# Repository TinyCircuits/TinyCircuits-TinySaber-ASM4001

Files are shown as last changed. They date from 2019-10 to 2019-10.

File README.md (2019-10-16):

# TinyCircuits-TinySaber-ASM4001
# ASM4001 Rev3

The design files are located under design_files/ for the TinyCircuits ASM4001 Rev 3 PCB. This is a touch-sensitive TinySaber made with RGB LEDs powered by Arduino software.

Format is in Cadsoft Eagle format - Eagle version 6.2 was used for the original design.

For more infomation on this, check out the product page at TinyCircuits.com: https://tinycircuits.com/collections/all/products/pocket-arcade

# License:

Design by TinyCircuits.
All design files are released under the Creative Commons Attribution Share-Alike 3.0 License, see the following link for details: http://creativecommons.org/licenses/by-sa/3.0

All text above must be included in any redistribution or derived design

This project uses designs and concepts developed as part of the Arduino project and the LilyPad project. The TinyCircuits design files themselves (schematics, PCB and libraries) are not directly derived from these works' design files and have been created new, however the concepts and basic architecture behind the TinyDuino and TinyLily products are derived and we thank the hard work of the organizations below for their contributions to open-source hardware:
  
Original Arduino Uno Design by Team Arduino

LilyPad Arduino Design by Leah Buechley and Sparkfun Electronics

Please support the open-source hardware community

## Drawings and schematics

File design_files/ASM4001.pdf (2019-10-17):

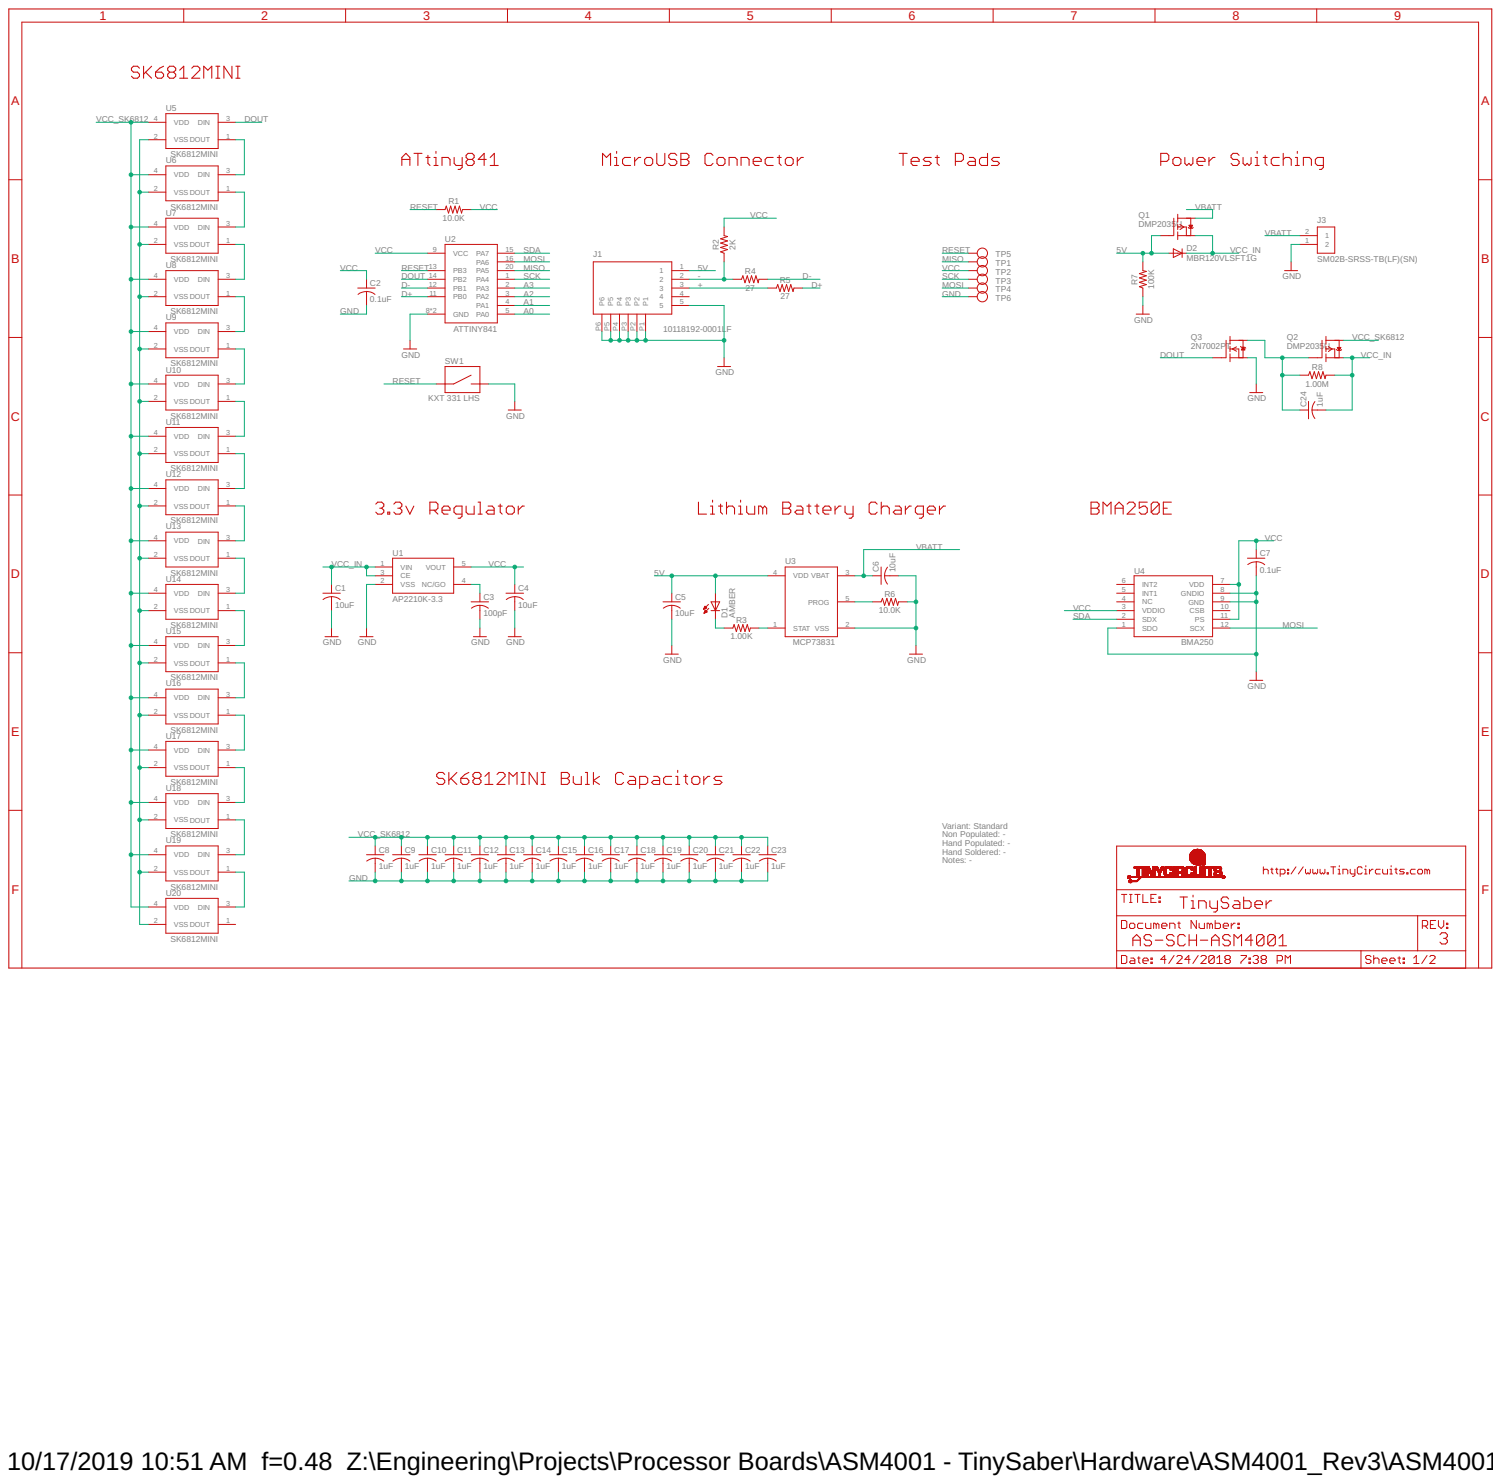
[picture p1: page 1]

SM02B-SRSS-TB(LF)(SN) DMP2035U

Variant: Standard Non Populated: - Hand Populated: - Hand Soldered: - Notes: -

10/17/2019 10:51 AM f=0.48 Z:\Engineering\Projects\Processor Boards\ASM4001 - TinySaber\Hardware\ASM4001_Rev3\ASM4001.sch (Sheet: 1/2)

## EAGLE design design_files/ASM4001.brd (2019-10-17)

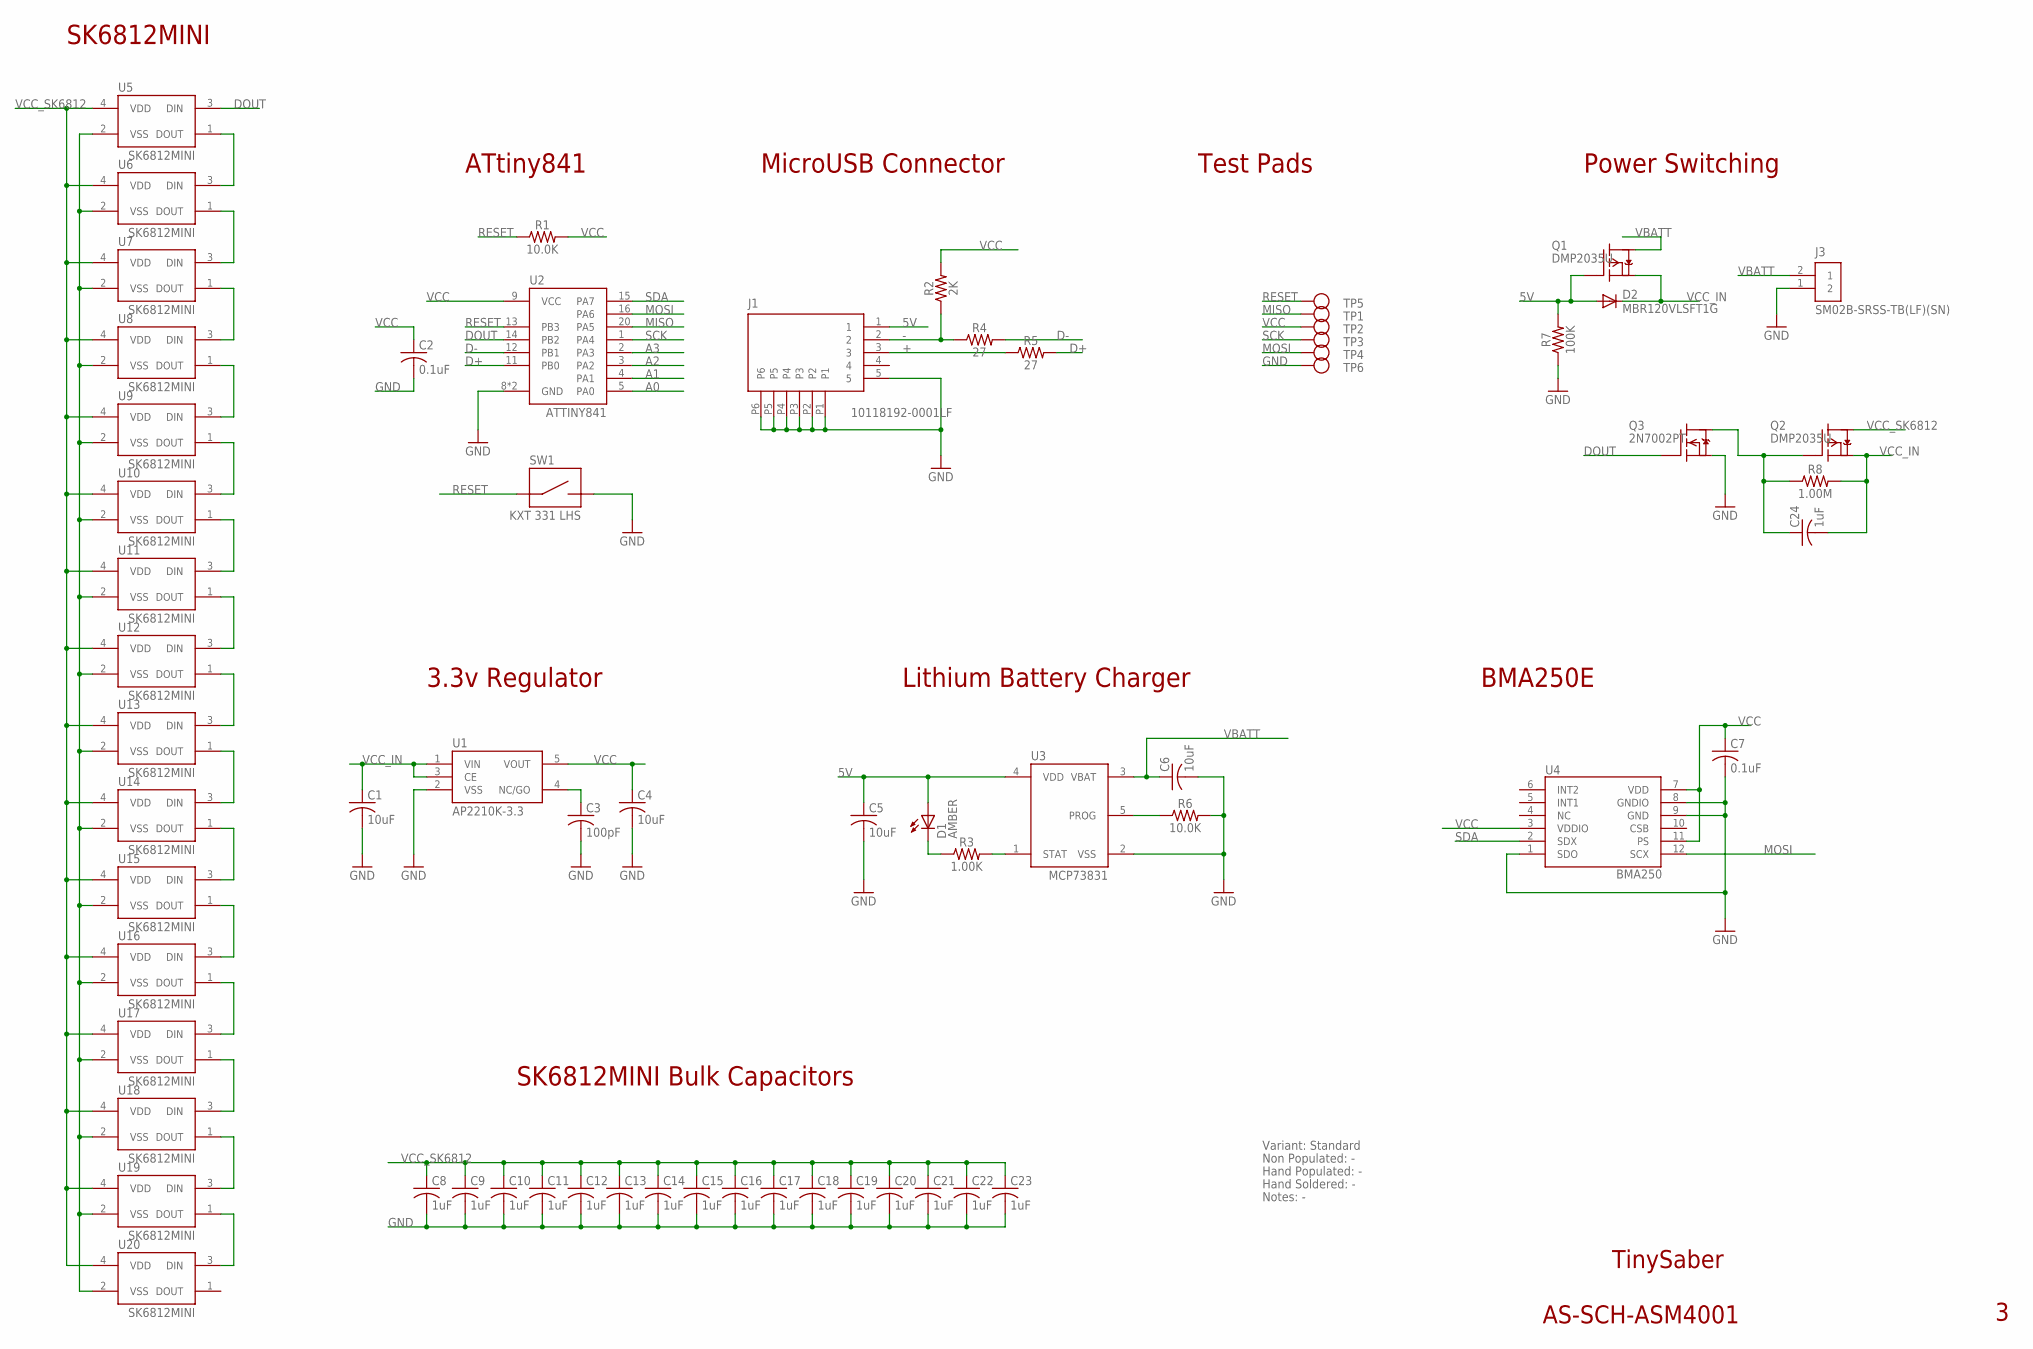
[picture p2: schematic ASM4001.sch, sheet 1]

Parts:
C1, C4, C5: 10uF; C0603; PARTNO AS-ITM-00002
C2, C7: 0.1uF; C0402
C3: 100pF; 0402; PARTNO AS-ITM-00148
C6: 10uF; C0603
C8, C9, C10, C11, C12, C13, C14, C15, C16, C17, C18, C19, C20, C21, C22, C23: 1uF; C0603; PARTNO AS-ITM-00410
C24: 1uF; C0402
D1: AMBER; 0402_LED
D2: MBR120VLSFT1G; SOD-123FL; PARTNO AS-ITM-00111
J1: 10118192-0001LF; MICRO_USB_ALT
J3: SM02B-SRSS-TB(LF)(SN); JST_SH_2X1
Q1: DMP2035U; SOT23
Q2: DMP2035U; SOT23A; PARTNO AS-ITM-00024
Q3: 2N7002PT; SOT-416
R1, R6: 10.0K; 0402
R2: 2K; 0402
R3: 1.00K; 0402
R4, R5: 27; 0402; PARTNO AS-ITM-00240
R7: 100K; 0402
R8: 1.00M; 0402; PARTNO AS-ITM-00005
SW1: KXT 331 LHS; KXT_LHS
TP1, TP2, TP3, TP4, TP5, TP6: TEST_POINT; TEST_POINT_1MM
U1: AP2210K-3.3; SOT-25; PARTNO AS-ITM-00344
U2: ATTINY841; VQFN-20
U3: MCP73831; SOT-23
U4: BMA250; 3-AXIS_ACCELEROMETER
U5, U6, U7, U8, U9, U10, U11, U12, U13, U14, U15, U16, U17, U18, U19, U20: SK6812MINI; PARTNO AS-ITM-00343

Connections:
5V: C5.1, D1.1 (A), D2.A, J1.1, Q1.B (G), R7.2, U3.4 (VDD)
+: J1.3, R5.1
-: J1.2, R2.1, R4.1
A0: U2.5 (PA0)
A1: U2.4 (PA1)
A2: U2.3 (PA2)
A3: U2.2 (PA3)
D+: R5.2, U2.11 (PB0)
D-: R4.2, U2.12 (PB1)
DOUT: Q3.1 (G), U2.14 (PB2), U5.3 (DIN)
GND: C1.2, C2.2, C3.2, C4.2, C5.2, C6.2, C7.2, C8.2, C9.2, C10.2, C11.2, C12.2, C13.2, C14.2, C15.2, C16.2, C17.2, C18.2, C19.2, C20.2, C21.2, C22.2, C23.2, J1.5, J1.P1, J1.P2, J1.P3, J1.P4, J1.P5, J1.P6, J3.1 (2), Q3.2 (S), R6.2, R7.1, SW1.2, TP6.P$1, U1.2 (VSS), U2.8 (GND), U2.PAD (GND), U3.2 (VSS), U4.1 (SDO), U4.8 (GNDIO), U4.9 (GND), U5.2 (VSS), U6.2 (VSS), U7.2 (VSS), U8.2 (VSS), U9.2 (VSS), U10.2 (VSS), U11.2 (VSS), U12.2 (VSS), U13.2 (VSS), U14.2 (VSS), U15.2 (VSS), U16.2 (VSS), U17.2 (VSS), U18.2 (VSS), U19.2 (VSS), U20.2 (VSS)
MISO: TP1.P$1, U2.20 (PA5)
MOSI: TP4.P$1, U2.16 (PA6), U4.12 (SCX)
unnamed: C3.1, U1.4 (NC/GO)
unnamed: U17.1 (DOUT), U18.3 (DIN)
unnamed: U18.1 (DOUT), U19.3 (DIN)
unnamed: U6.1 (DOUT), U7.3 (DIN)
unnamed: C24.1, Q2.B (G), Q3.3 (D), R8.1
unnamed: U19.1 (DOUT), U20.3 (DIN)
unnamed: R6.1, U3.5 (PROG)
unnamed: U5.1 (DOUT), U6.3 (DIN)
unnamed: U7.1 (DOUT), U8.3 (DIN)
unnamed: U8.1 (DOUT), U9.3 (DIN)
unnamed: R3.2, U3.1 (STAT)
unnamed: D1.2 (C), R3.1
unnamed: U9.1 (DOUT), U10.3 (DIN)
unnamed: U10.1 (DOUT), U11.3 (DIN)
unnamed: U11.1 (DOUT), U12.3 (DIN)
unnamed: U12.1 (DOUT), U13.3 (DIN)
unnamed: U13.1 (DOUT), U14.3 (DIN)
unnamed: U14.1 (DOUT), U15.3 (DIN)
unnamed: U15.1 (DOUT), U16.3 (DIN)
unnamed: U16.1 (DOUT), U17.3 (DIN)
RESET: R1.1, SW1.1, TP5.P$1, U2.13 (PB3)
SCK: TP3.P$1, U2.1 (PA4)
SDA: U2.15 (PA7), U4.2 (SDX)
VBATT: C6.1, J3.2 (1), Q1.C (D), U3.3 (VBAT)
VCC: C2.1, C4.1, C7.1, R1.2, R2.2, TP2.P$1, U1.5 (VOUT), U2.9 (VCC), U4.3 (VDDIO), U4.7 (VDD), U4.11 (PS)
VCC_IN: C1.1, C24.2, D2.C, Q1.E (S), Q2.E (S), R8.2, U1.1 (VIN), U1.3 (CE)
VCC_SK6812: C8.1, C9.1, C10.1, C11.1, C12.1, C13.1, C14.1, C15.1, C16.1, C17.1, C18.1, C19.1, C20.1, C21.1, C22.1, C23.1, Q2.C (D), U5.4 (VDD), U6.4 (VDD), U7.4 (VDD), U8.4 (VDD), U9.4 (VDD), U10.4 (VDD), U11.4 (VDD), U12.4 (VDD), U13.4 (VDD), U14.4 (VDD), U15.4 (VDD), U16.4 (VDD), U17.4 (VDD), U18.4 (VDD), U19.4 (VDD), U20.4 (VDD)

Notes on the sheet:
TinySaber
AS-SCH-ASM4001
Test Pads
MicroUSB Connector
ATtiny841
Power Switching
3.3v Regulator
Lithium Battery Charger
BMA250E
SK6812MINI
SK6812MINI Bulk Capacitors
Variant: Standard
Non Populated: -
Hand Populated: -
Hand Soldered: -
Notes: -

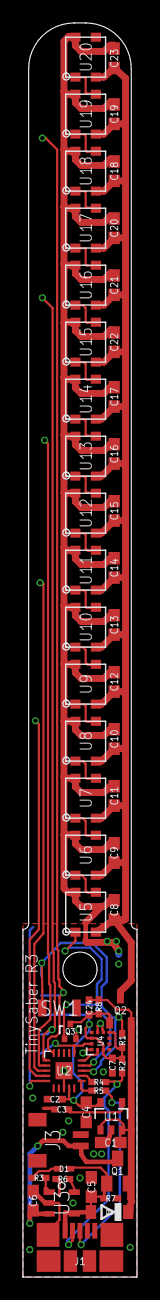
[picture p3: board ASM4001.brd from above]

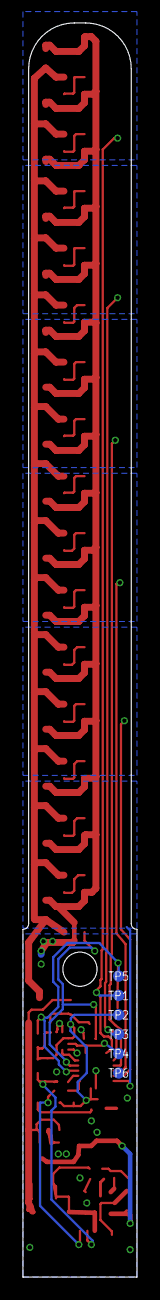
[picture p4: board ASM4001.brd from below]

Board: 2 copper layers, 10.0 x 110.0 mm, 67 parts (6 on the bottom side), 36 nets.

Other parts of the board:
U$1: DOCFIELD-TINYCIRCUITS-PCB

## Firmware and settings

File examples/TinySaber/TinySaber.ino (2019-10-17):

//-------------------------------------------------------------------------------
//  TinyCircuits TinySaber Firmware
//
//  TinySaber is a fun, low cost kit that is effectively a development board for
//  the ATtiny841 micro with 16 RGB LEDs, capacitive touch pads, an accelerometer,
//  software USB and other features. Arduino/any support for this is only possible
//  due to a few key projects:
//  Micronucleus bootloader: https://github.com/micronucleus/micronucleus
//  Digistump: http://digistump.com/ , https://github.com/digistump/DigistumpArduino
//  ATTinyCore: https://github.com/SpenceKonde/ATTinyCore
//
//  Changelog:
//  1.0.0 5 July 2017 Initial release
//
//  Written by Ben Rose for TinyCircuits, http://TinyCircuits.com
//
//-------------------------------------------------------------------------------

#include "light_ws2812.h"
#include "light_ws2812.c"
#include "BMA250.h"
#include "capTouch.h"

BMA250 accel;
capTouch touch;

/*
  Notes:
  Accel X is left/right wave
  Accel Y is up/down
  LED write = 550us
  Accel read = 300us
  LEDs are 0-15 extending from handle
  Sensors are 0-5 extending from handle
*/

#define text1Line1 "Tiny "
#define text1Line2 "Saber"

#define text2Line1 "Maker"
#define text2Line2 "Faire"

#define text3Big   "TinyCircuits"

#define LEDCount  16

struct cRGB led[LEDCount];
const struct cRGB red = {255, 0, 0};
const struct cRGB green = {0, 255, 0};
const struct cRGB blue = {0, 0, 255};
const struct cRGB white = {255, 255, 255};
const struct cRGB off = {0, 0, 0};

const uint8_t saberMode = 1;
const uint8_t rainbowMode = 2;
const uint8_t flashLightMode = 3;
const uint8_t textMode = 4;
uint8_t mode = 0;

int saberColor = 0;

void setup(void) {
  delay(100);
  touch.begin();
  delay(100);
  accel.begin(BMA250_range_8g, BMA250_update_time_4ms);
  accel.read();

  memset(led, 0, sizeof(led));
  changeMode(saberMode);
}


void loop() {
  accel.read();

  int completedTouch = touch.read();

  if (mode == saberMode) {
    saberModeLoop(touch.getMaxReading(), touch.scaleToRange(LEDCount - 1));
  } else if (mode == rainbowMode) {
    rainbowLoop();
  } else if (mode == flashLightMode) {
    //
  } else if (mode == textMode) {
    POVLoop();
  } else if (!mode) {
    //sleepMode
  }


  if (completedTouch) {
    if (touch.initialTouchPos == 0 && touch.finalTouchPos == 5) {
      if (touch.allTouchedPositions == (TS(5) | TS(4) | TS(3) | TS(2) | TS(1) | TS(0))) {
        changeMode(saberMode);
      }
    } else if (touch.initialTouchPos >= 4 && touch.finalTouchPos == 0) {
      if (touch.allTouchedPositions == (TS(5) | TS(4) | TS(3) | TS(2) | TS(1) | TS(0)) ||
          touch.allTouchedPositions == (TS(4) | TS(3) | TS(2) | TS(1) | TS(0))) {
        changeMode(0);
      }
    } else if (touch.duration() > 70 && touch.duration() < 400) {
      if (mode) {
        changeMode(saberMode);
      }
    }
  }
  if (mode) {
    if (touch.currentTouchedPositions == (TS(5) | TS(0)))
      changeMode(flashLightMode);

    if (touch.currentTouchedPositions == (TS(2) | TS(0)))
      changeMode(rainbowMode);

    if (touch.currentTouchedPositions == (TS(3) | TS(0)))
      changeMode(textMode);
  }

  ws2812_sendarray((uint8_t *)led, LEDCount * 3);
}

uint32_t changeModeTimeout = 0xFFFF;

void changeMode(uint8_t newMode) {
  if (millis() - changeModeTimeout < 500) return;
  if (newMode == mode)return;
  changeModeTimeout = millis();
  accel.clearInterrupt();
  if (newMode == saberMode) {
    fadeTo(off);
    saberModeInit();
    for (uint8_t j = 0; j < 16; j++) {
      if (saberColor == 0) {
        led[j].r = 5;
      } 
      if (saberColor == 1) {
        led[j].g = 5;
      }
      if (saberColor == 2) {
        led[j].b = 5;
      }
      ws2812_sendarray((uint8_t *)led, LEDCount * 3);
      delay(30);
    }
  } else if (newMode == rainbowMode) {
    rainbowLoop();
  } else if (newMode == flashLightMode) {
    fadeTo(white);
  } else if (newMode == textMode) {
  } else if (!newMode) {
    fadeTo(off);
  }
  mode = newMode;
}

void fadeTo(struct cRGB color) {
  uint8_t done = false;
  uint16_t i;
  while (!done) {
    done = true;
    for (i = 0; i < LEDCount; i++) {
      if (led[i].r != color.r) {
        done = false;
        if (led[i].r < color.r) {
          led[i].r++;
        } else {
          led[i].r--;
        }
      }
      if (led[i].g != color.g) {
        done = false;
        if (led[i].g < color.g) {
          led[i].g++;
        } else {
          led[i].g--;
        }
      }
      if (led[i].b != color.b) {
        done = false;
        if (led[i].b < color.b) {
          led[i].b++;
        } else {
          led[i].b--;
        }
      }
    }
    if (!done)ws2812_sendarray((uint8_t *)led, LEDCount * 3);
    if (!done)delay(3);
  }
}

uint32_t rainbowTimer = 0;
uint8_t rainbowCount = 0;

void rainbowLoop() {
  if (millis() - rainbowTimer < 30) return;
  rainbowTimer = millis();
  uint16_t i;
  for (i = 0; i < LEDCount; i++) {
    Wheel(i, (i + rainbowCount) * 4 & 255);
  }
  rainbowCount++;
}

// Input a value 0 to 255 to get a color value.
// The colours are a transition r - g - b - back to r.
void Wheel(uint8_t i, uint8_t WheelPos) {
  WheelPos = 255 - WheelPos;
  if (WheelPos < 85) {
    led[i].r = (uint16_t)(255 - WheelPos * 3);
    led[i].g = (uint16_t)(0);
    led[i].b = (uint16_t)(WheelPos * 3);
  } else if (WheelPos < 170) {
    WheelPos -= 85;
    led[i].r = (uint16_t)(0);
    led[i].g = (uint16_t)(WheelPos * 3);
    led[i].b = (uint16_t)(255 - WheelPos * 3);
  } else {
    WheelPos -= 170;
    led[i].r = (uint16_t)(WheelPos * 3);
    led[i].g = (uint16_t)(255 - WheelPos * 3);
    led[i].b = (uint16_t)(0);
  }
  return;
}
